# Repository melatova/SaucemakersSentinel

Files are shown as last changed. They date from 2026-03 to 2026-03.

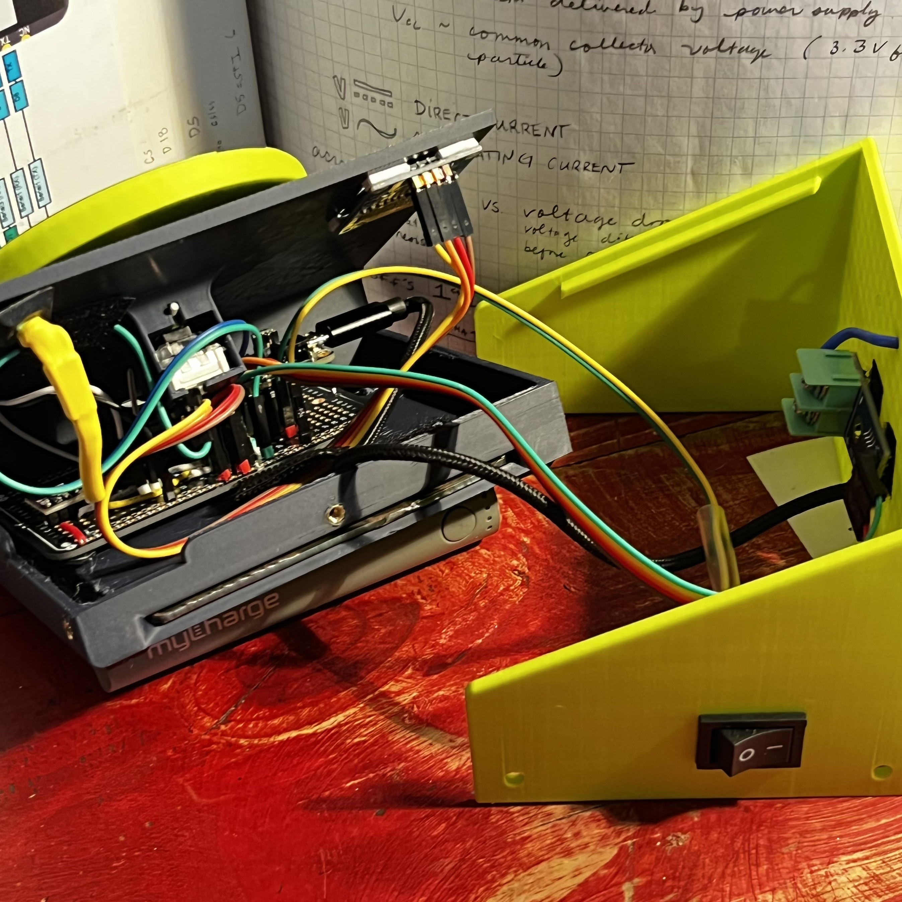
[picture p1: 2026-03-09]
Sentinel_IoT_Device/docs/assembly2.jpg

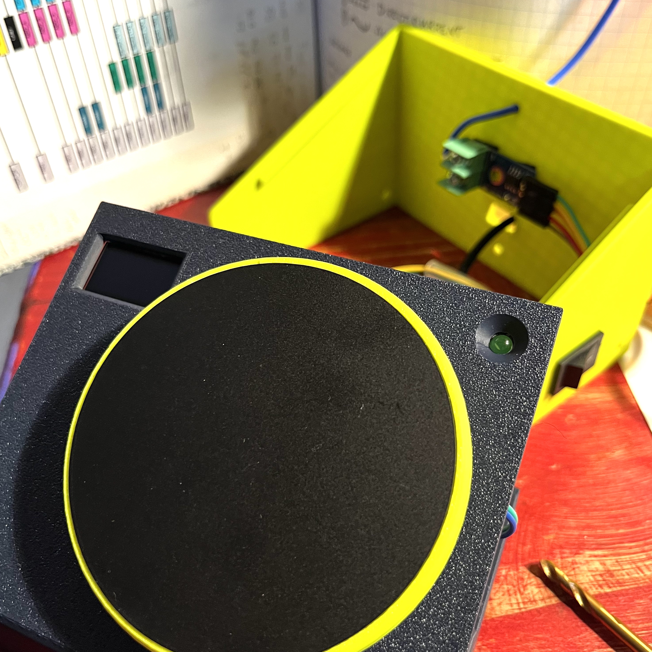
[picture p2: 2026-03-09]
Sentinel_IoT_Device/docs/assembly.jpg

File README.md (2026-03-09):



[]()
[]()

-------------------------------------------
--        Saucier’s Sentinel README      --
-------------------------------------------
          (^ . ^)  welcome!

Saucier’s Sentinel — A Hot Process Timer

A chef‑friendly IoT device that monitors a 10‑minute hot‑process cycle for sauce making.  
It reads a K‑type thermocouple, calculates the local boiling point from air pressure,  
and alerts the chef with a playful OLED UI, LED blinks, Philips Hue bulbs, and Wemo smart plugs.

* * * * * * * * * * * * * * * *

Features

  * Precise temperature monitoring** using a MAX6675 K‑type thermocouple  
  * Local boiling‑point calculation** using real‑time pressure from a BME280  
  * Chef‑friendly OLED UI** with animations, progress bar, and alert screens  
  * Smart kitchen integration**  
  * Philips Hue bulbs (blue = too cold, red = too hot)  
  * Wemo smart plugs (radio alert + stove cutoff)  
  * Single‑button interface**  
  * Short press -> start  
  * Long press -> cancel  
  * Stable state machine** for stable, predictable behavior  
  * Custom 3D‑printed enclosure** with slanted front, big easy-to-hit button and OLED window  

······························

System Architecture

loop()
├── readSensors()
├── updateButtons()
├── runStateMachine()
├── updateAlerts()
├── updateLED()
└── updateDisplay()

······························

Hardware

  * Particle Photon 2**
  * MAX6675 thermocouple amplifier**
  * K‑type thermocouple probe**
  * BME280 pressure + humidity sensor**
  * 128×64 SSD1306 OLED (I²C)**
  * Wemo smart plugs**
  * Philips Hue bulbs**
  * Custom 3D‑printed enclosure**

······························

Pinout

| Component | Pin |
|---|-----|
| Button | D6  |  
| LED | D7  |
| Thermocouple CS | D5  |
| Thermocouple SCK  | D4  |
| Thermocouple MISO | D3  |
| OLED SDA | D0  |
| OLED SCL | D1  |
| BME280 SDA | D0  |
| BME280 SCL | D1  |

······························

Local Boiling Point Calculation  
*(Clausius‑Clapeyron equation)*

```cpp
float calcBoilingPointC(float pressPA) {
    float pressHPA = pressPA / 100.0;
    float L  = 40650.0;
    float R  = 8.314;
    float T0 = 373.15;
    float P0 = 1013.25;

    float invT = (1.0 / T0) - (logf(pressHPA / P0) * R / L);
    return (1.0 / invT) - 273.15;
}

case SCREEN_CYCLE_IN_PROGRESS:
    if (cycleTimer.isTimerReady()) {
        currentScreen = SCREEN_SUCCESS;
        break;
    }
    if (tempF < TEMP_SAFE_LOW)  currentScreen = SCREEN_ALERT_LOW;
    if (tempF > TEMP_SAFE_HIGH) currentScreen = SCREEN_ALERT_HIGH;
    if (wasCancelHeld()) {
        cancelTimer.startTimer(CANCEL_MS);
        currentScreen = SCREEN_CANCELLING;
    }
    break;

······························

State Machine Core

case SCREEN_CYCLE_IN_PROGRESS:
    if (cycleTimer.isTimerReady()) {
        currentScreen = SCREEN_SUCCESS;
        break;
    }
    if (tempF < TEMP_SAFE_LOW)  currentScreen = SCREEN_ALERT_LOW;
    if (tempF > TEMP_SAFE_HIGH) currentScreen = SCREEN_ALERT_HIGH;
    if (wasCancelHeld()) {
        cancelTimer.startTimer(CANCEL_MS);
        currentScreen = SCREEN_CANCELLING;
    }
    break;

······························

OLED UI

Animated steam on loading screen

Big friendly temperature banner

Progress bar during cycle

Shiver animation (too cold)

Flame flicker (too hot)

Spinner animation (cancelling)

Sparkle animation (success)

······························

Enclosure

Designed in Onshape with:

Slanted ergonomic front

OLED window

Button recess

Thermocouple exit port

Internal mounting bosses

Smooth face blends and fillets

······························

Gallery

Enclosure files
(SaucemakersSentinel/Sentinel_IoT_device/enclosure/)

Internal layout
(SaucemakersSentinel/Sentinel_IoT_device/docs/Temp_monitor_device_fritzing_bb.png)
(SaucemakersSentinel/Sentinel_IoT_device/docs/Temp_monitor_device_fritzing_schem.png)

OLED UI photos
(SaucemakersSentinel/Sentinel_IoT_device/images/OLED_display.png)
(SaucemakersSentinel/Sentinel_IoT_device/images/OLED_Temp_Low.MOV)
(SaucemakersSentinel/Sentinel_IoT_device/images/OLED_complete.MOV)

Thermocouple in pot
(SaucemakersSentinel/Sentinel_IoT_device/images/Habanero_sauce.png)

Final assembled device 
(SaucemakersSentinel/Sentinel_IoT_device/images/device_with_active_screen_front.jpg)

······························

Files

/src — firmware

/enclosure — STLs

/images — photos + renders

/docs — diagrams + schematics

······························

Why This Exists
This project was created for a very special emerging hot‑sauce chef
who needed a reliable, friendly, and scientifically accurate way
to monitor the hot‑process cycle.

······························

License
MIT License — enjoy, remix, and cook boldly.

Project write‑up on Hackster.io:
https://www.hackster.io/melatova/saucier-s-sentinel-hot-process-timer-f0ca6f

[![Hackster Project](https://img.shields.io/badge/Hackster-Project-blue)](https://www.hackster.io/melatova/saucier-s-sentinel-hot-process-timer-f0ca6f)

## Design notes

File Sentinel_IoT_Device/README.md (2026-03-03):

# Sentinel_IoT_Device

This firmware project was created using [Particle Developer Tools](https://www.particle.io/developer-tools/) and is compatible with all [Particle Devices](https://www.particle.io/devices/).

Feel free to replace this README.md file with your own content, or keep it for reference.

## Table of Contents
- [Introduction](#introduction)
- [Prerequisites To Use This Template](#prerequisites-to-use-this-repository)
- [Getting Started](#getting-started)
- [Particle Firmware At A Glance](#particle-firmware-at-a-glance)
  - [Logging](#logging)
  - [Setup and Loop](#setup-and-loop)
  - [Delays and Timing](#delays-and-timing)
  - [Testing and Debugging](#testing-and-debugging)
  - [GitHub Actions (CI/CD)](#github-actions-cicd)
  - [OTA](#ota)
  - [Assets](#assets)
  - [Environment](#environment)
- [Support and Feedback](#support-and-feedback)
- [Version](#version)

## Introduction

For an in-depth understanding of this project template, please refer to our [documentation](https://docs.particle.io/firmware/best-practices/firmware-template/).

## Prerequisites To Use This Repository

To use this software/firmware on a device, you'll need:

- A [Particle Device](https://www.particle.io/devices/).
- Windows/Mac/Linux for building the software and flashing it to a device.
- [Particle Development Tools](https://docs.particle.io/getting-started/developer-tools/developer-tools/) installed and set up on your computer.
- Optionally, a nice cup of tea (and perhaps a biscuit).

## Getting Started

1. While not essential, we recommend running the [device setup process](https://setup.particle.io/) on your Particle device first. This ensures your device's firmware is up-to-date and you have a solid baseline to start from.

2. If you haven't already, open this project in Visual Studio Code (File -> Open Folder). Then [compile and flash](https://docs.particle.io/getting-started/developer-tools/workbench/#cloud-build-and-flash) your device. Ensure your device's USB port is connected to your computer.

3. Verify the device's operation by monitoring its logging output:
    - In Visual Studio Code with the Particle Plugin, open the [command palette](https://docs.particle.io/getting-started/developer-tools/workbench/#particle-commands) and choose "Particle: Serial Monitor".
    - Or, using the Particle CLI, execute:
    ```
    particle serial monitor --follow
    ```

4. Uncomment the code at the bottom of the cpp file in your src directory to publish to the Particle Cloud! Login to console.particle.io to view your devices events in real time.

5. Customize this project! For firmware details, see [Particle firmware](https://docs.particle.io/reference/device-os/api/introduction/getting-started/). For information on the project's directory structure, visit [this link](https://docs.particle.io/firmware/best-practices/firmware-template/#project-overview).

## Particle Firmware At A Glance

### Logging

The firmware includes a [logging library](https://docs.particle.io/reference/device-os/api/logging/logger-class/). You can display messages at different levels and filter them:

```
Log.trace("This is trace message");
Log.info("This is info message");
Log.warn("This is warn message");
Log.error("This is error message");
```

### Setup and Loop

Particle projects originate from the Wiring/Processing framework, which is based on C++. Typically, one-time setup functions are placed in `setup()`, and the main application runs from the `loop()` function.

For advanced scenarios, explore our [threading support](https://docs.particle.io/firmware/software-design/threading-explainer/).

### Delays and Timing

By default, the setup() and loop() functions are blocking whilst they run, meaning that if you put in a delay, your entire application will wait for that delay to finish before anything else can run. 

For techniques that allow you to run multiple tasks in parallel without creating threads, checkout the code example [here](https://docs.particle.io/firmware/best-practices/firmware-template/).

(Note: Although using `delay()` isn't recommended for best practices, it's acceptable for testing.)

### Testing and Debugging

For firmware testing and debugging guidance, check [this documentation](https://docs.particle.io/troubleshooting/guides/build-tools-troubleshooting/debugging-firmware-builds/).

### GitHub Actions (CI/CD)

This project provides a YAML file for GitHub, automating firmware compilation whenever changes are pushed. More details on [Particle GitHub Actions](https://docs.particle.io/firmware/best-practices/github-actions/) are available.

### OTA

To learn how to utilize Particle's OTA service for device updates, consult [this documentation](https://docs.particle.io/getting-started/cloud/ota-updates/).

Test OTA with the 'Particle: Cloud Flash' command in Visual Studio Code or the CLI command 'particle flash'!

This firmware supports binary assets in OTA packages, allowing the inclusion of audio, images, configurations, and external microcontroller firmware. More details are [here](https://docs.particle.io/reference/device-os/api/asset-ota/asset-ota/).

### Assets

To include assets in your OTA bundle, create an `assets` folder in your project root and place your files there. These can include audio files, images, configuration files, or firmware for external microcontrollers.

To enable asset OTA, uncomment the following line in `project.properties`:
```
assetOtaDir=assets
```

See the [Asset OTA documentation](https://docs.particle.io/reference/device-os/api/asset-ota) for more details.

### Environment

To bundle environment variables with your firmware, create an `env.json` file in your project root. Uncomment the following line in `project.properties` to enable it:
```
env=env.json
```

See the [Environment documentation](https://docs.particle.io/reference/device-os/api/environment) for more details.

## Support and Feedback

For support or feedback on this template or any Particle products, please join our [community](https://community.particle.io)!

## Version

Template version 1.0.3

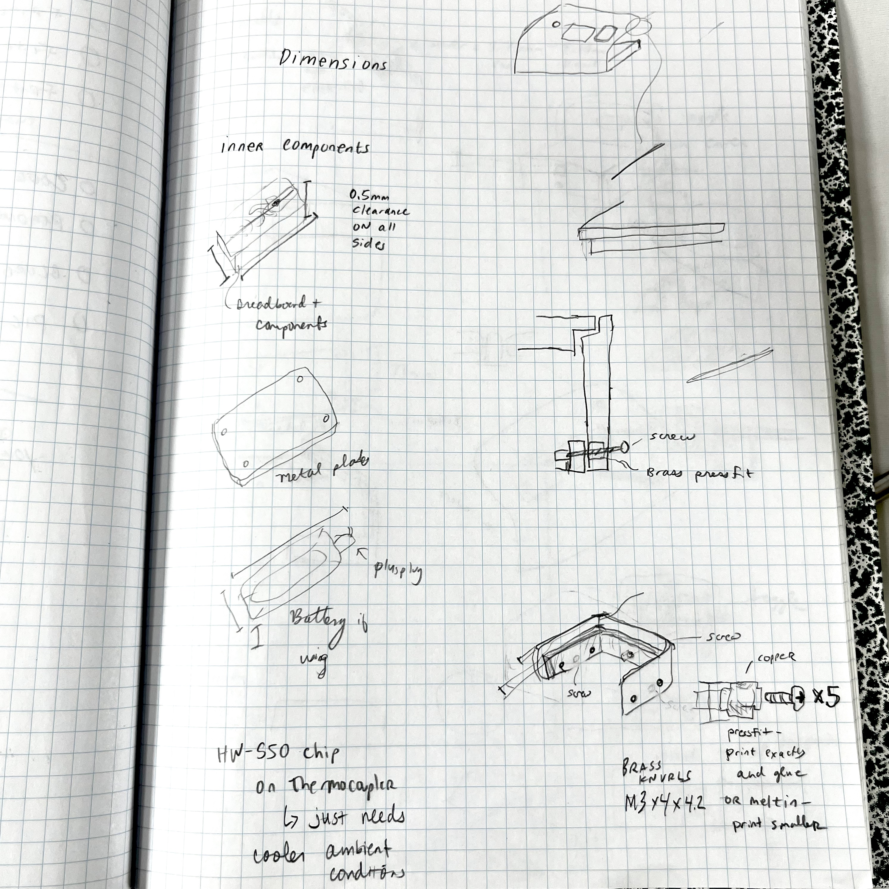
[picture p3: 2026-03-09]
Sentinel_IoT_Device/docs/Sketch_box_back.jpg

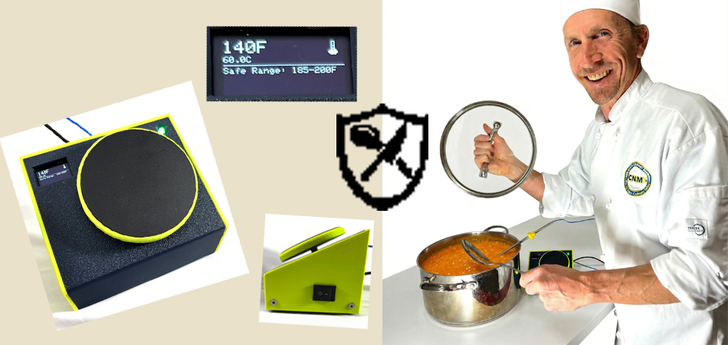
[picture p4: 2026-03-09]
Sentinel_IoT_Device/images/hackster_main.png

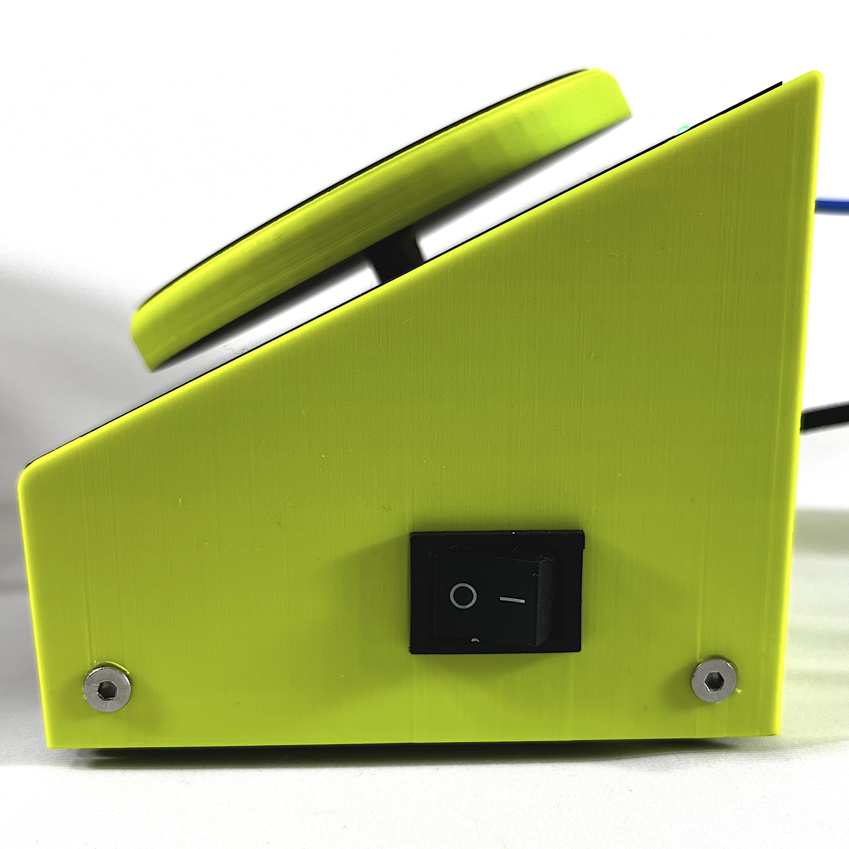
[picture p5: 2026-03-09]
Sentinel_IoT_Device/images/box_right_side.jpg

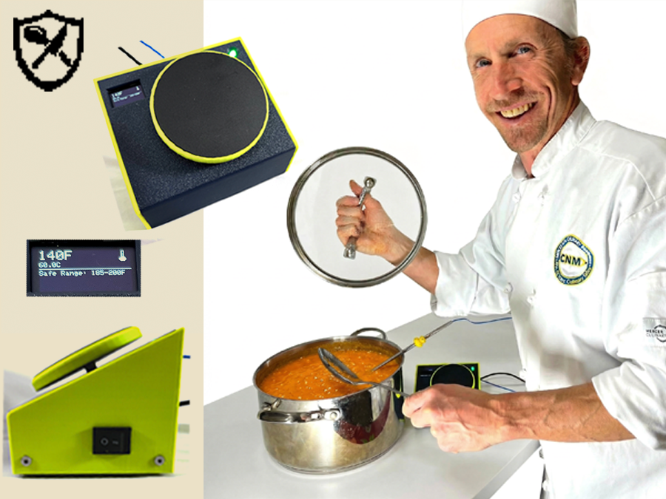
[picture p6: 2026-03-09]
Sentinel_IoT_Device/images/hackster_main2.png

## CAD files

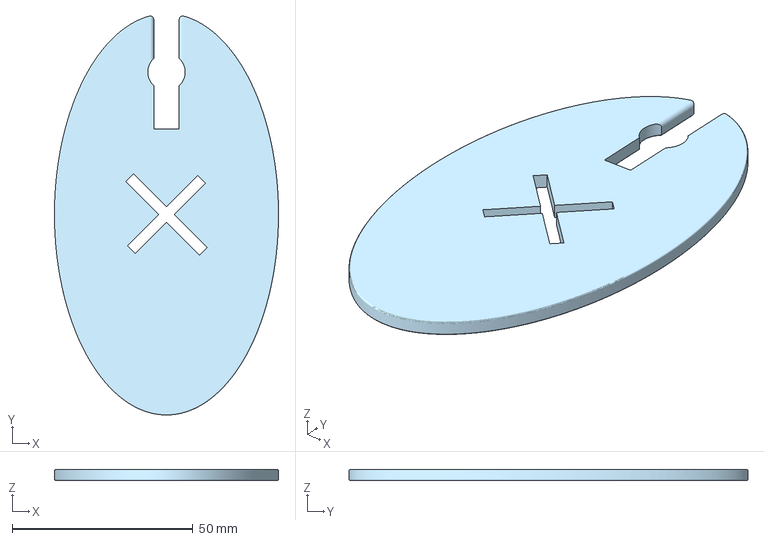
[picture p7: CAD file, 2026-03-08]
Sentinel_IoT_Device/docs/Duck holder - Part 1.3mf
62.0 x 110.4 x 3.00 mm

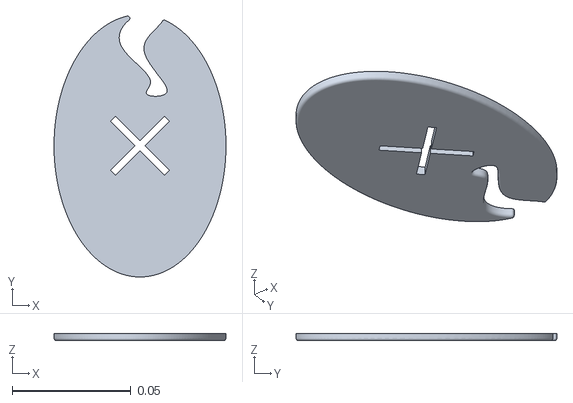
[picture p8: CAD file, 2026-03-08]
Sentinel_IoT_Device/enclosure/Duck holder - Part 2.stl
0.0725 x 0.11 x 0.003

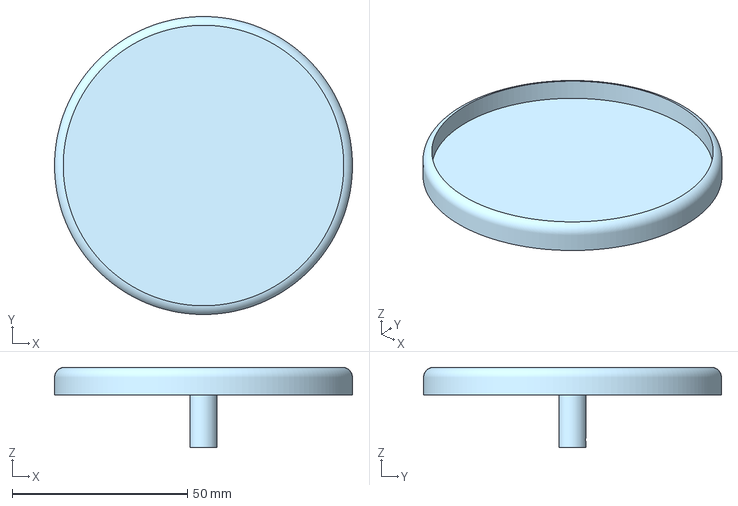
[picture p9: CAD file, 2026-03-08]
Sentinel_IoT_Device/docs/OLED_BME_Therm_Enclosure_Button.3mf
85.0 x 85.0 x 23.0 mm

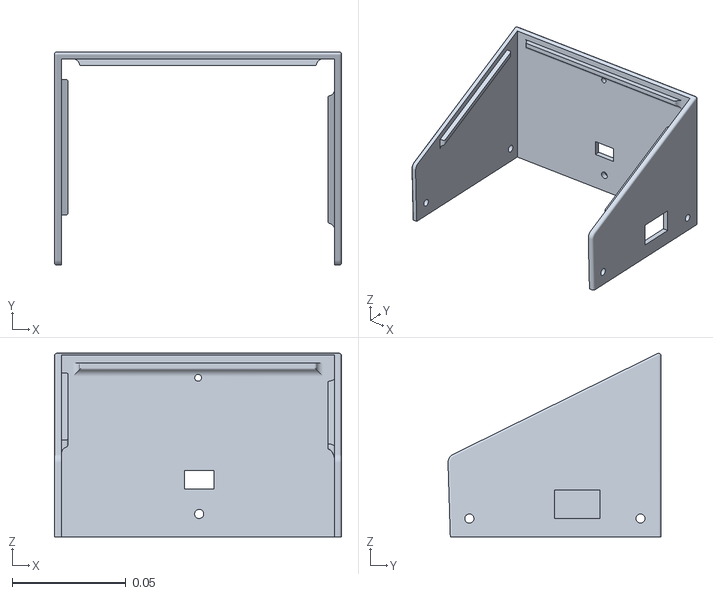
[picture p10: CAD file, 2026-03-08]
Sentinel_IoT_Device/enclosure/OLED_BME_Therm_Enclosure_Back.stl
0.126 x 0.0935 x 0.0806

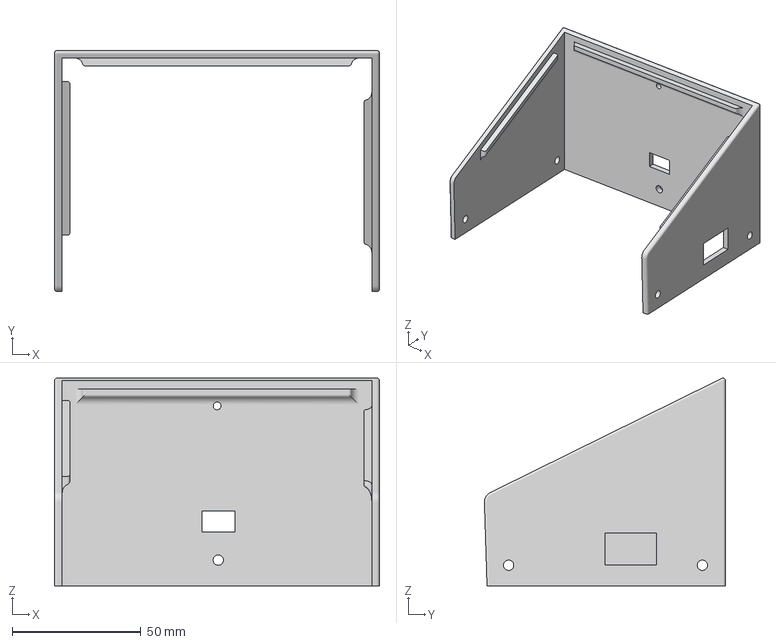
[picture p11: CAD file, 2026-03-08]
Sentinel_IoT_Device/docs/OLED_BME_Therm_Enclosure_Back.3mf
126.0 x 93.5 x 80.6 mm

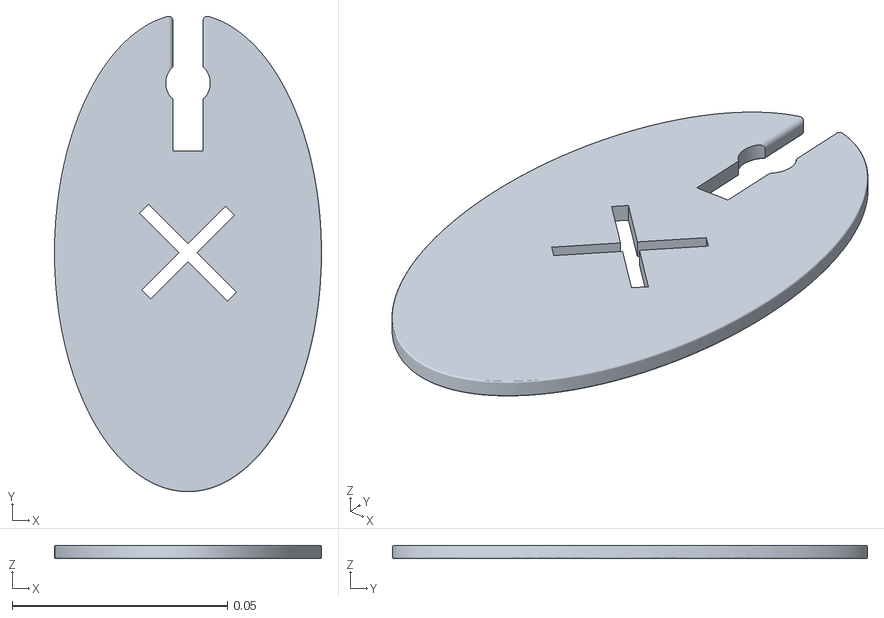
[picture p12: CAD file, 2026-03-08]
Sentinel_IoT_Device/enclosure/Duck holder - Part 1.stl
0.062 x 0.11 x 0.003

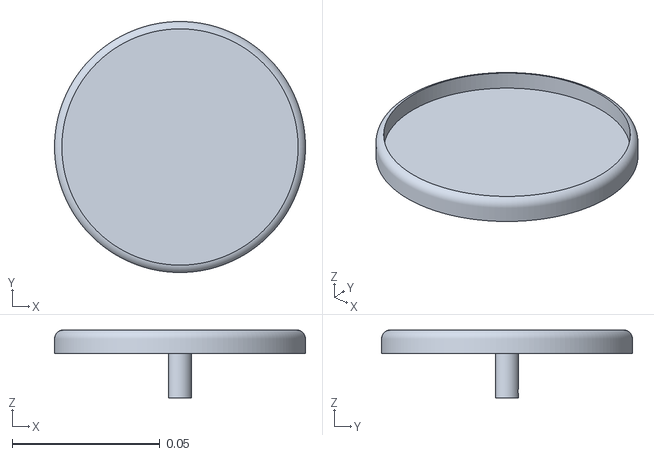
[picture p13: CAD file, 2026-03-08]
Sentinel_IoT_Device/enclosure/OLED_BME_Therm_Enclosure_Button.stl
0.085 x 0.085 x 0.023

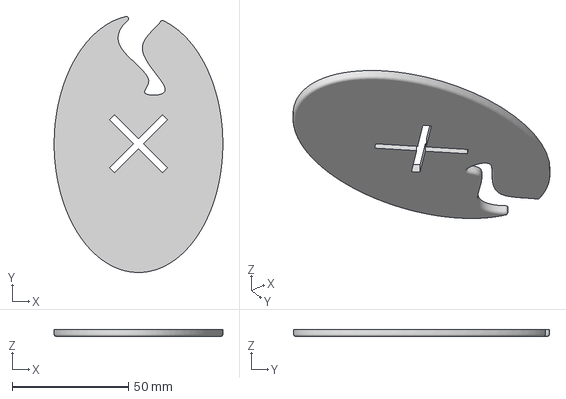
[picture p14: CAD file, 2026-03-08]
Sentinel_IoT_Device/docs/Duck holder - Part 2.3mf
72.5 x 109.9 x 3.00 mm

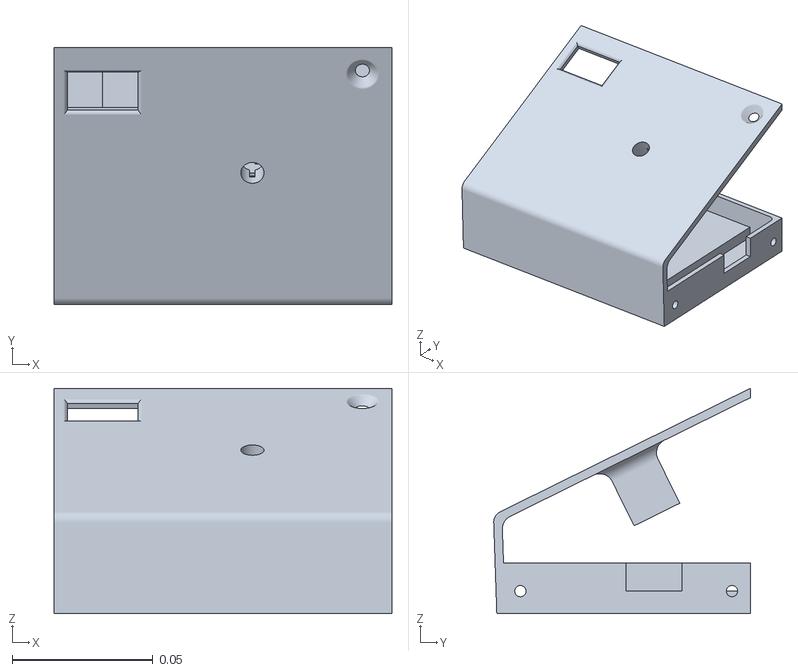
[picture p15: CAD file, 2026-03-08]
Sentinel_IoT_Device/enclosure/OLED_BME_Therm_Enclosure_Front.stl
0.12 x 0.0911 x 0.08

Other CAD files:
Sentinel_IoT_Device/docs/OLED_BME_Therm_Enclosure_Front.3mf

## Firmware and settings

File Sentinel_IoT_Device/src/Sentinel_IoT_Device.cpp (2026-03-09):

/*
 * Project:     Saucier’s Sentinel - Hot Process Timer
 * Author:      Nicole
 * Date:        03/07/2026
 *
 * Description:
 *   IoT temperature monitor for a 10-minute hot-process cycle.
 *   Tracks sauce temperature with a K-type thermocouple and alerts the
 *   chef via OLED display, Philips Hue bulbs, and Wemo smart plugs when
 *   the temperature drifts outside the safe range (185-200 degF).
 *   Also calculates the local boiling point from live air pressure —
 *   handy in Albuquerque, where water boils around 202 degF.
 *
 * Hardware pins:
 *   D7  — Power indicator LED (solid=idle, slow tick=timing, fast=done)
 *   D6  — Start/Cancel button (short press=start, hold 2s=cancel)
 *   D5  — Thermocouple CS   (MAX6675 chip select)
 *   D4  — Thermocouple SCK  (MAX6675 clock)
 *   D3  — Thermocouple MISO (MAX6675 data out)
 *   D1  — SCL: shared by OLED (SSD1306) and environment sensor (BME280)
 *   D0  — SDA: shared by OLED (SSD1306) and environment sensor (BME280)
 *   EN  — Hardware power switch
 *
 * Loop order every frame:
 *   readSensors → updateButtons → runStateMachine
 *   → updateAlerts → updateLED → updateDisplay
 *
 * Can change CYCLE_MS is set to 10000 (10 sec) for testing.
 *   Change to 600000 for the real 10-minute hot-process cycle.
 */


// ════════════════════════════════════════════════════════════════
//  LIBRARIES
// ════════════════════════════════════════════════════════════════

#include "Particle.h"
#include <math.h>              // logf() — used in boiling point calculation
#include "MAX6675.h"           // K-type thermocouple reader
#include "Adafruit_BME280.h"   // temperature / pressure / humidity sensor
#include "Adafruit_GFX.h"      // graphics resource (text, shapes)
#include "Adafruit_SSD1306.h"  // OLED display driver
#include "IoTTimer.h"          // non-blocking timers (no delay())
#include "bitmaps.h"           // original pixel art icons
#include "ui_theme.h"          // layout constants, font sizes, thresholds
#include "wemo.h"              // Wemo smart plug control
#include "hue.h"               // Philips Hue bulb control

SYSTEM_MODE(SEMI_AUTOMATIC);   // Call WiFi.connect() in setup()
SYSTEM_THREAD(ENABLED);        // keeps sensors and display responsive even if WiFi is slow


// ════════════════════════════════════════════════════════════════
//  DATA TYPES
// ════════════════════════════════════════════════════════════════

// The seven screens the device can be on at any moment.
// The state machine in runStateMachine() moves between these.
enum ScreenState {
    SCREEN_LOADING,            // loading screen while device warms up
    SCREEN_TEMP_MONITOR,       // idle — showing live temp, waiting to start
    SCREEN_CYCLE_IN_PROGRESS,  // timer running, temp in safe range
    SCREEN_ALERT_LOW,          // timer running, temp too cold
    SCREEN_ALERT_HIGH,         // timer running, temp too hot
    SCREEN_CANCELLING,         // chef held button — counting down to cancel
    SCREEN_SUCCESS,             // 10 minutes complete — safe to bottle!
    SCREEN_TIMER_SUCCESS        // 10 minutes complete! Just a kitchen timer.
};


// ════════════════════════════════════════════════════════════════
//  OBJECTS
// ════════════════════════════════════════════════════════════════

MAX6675          thermocouple;           // reads the probe in the pot
Adafruit_BME280  BME;                    // reads room pressure + humidity
Adafruit_SSD1306 display(-1);           // -1 = no hardware reset pin


// ════════════════════════════════════════════════════════════════
//  GLOBALS — constants
// ════════════════════════════════════════════════════════════════

// ── Hardware pins ────────────────────────────────────────────────
const int POWER_LEDPIN = D7;   // status LED
const int BUTTON_PIN   = D6;   // start/cancel button (INPUT_PULLUP: LOW=pressed)
const int BME_ADDRESS  = 0x76; // I2C address of BME280

// ── Hue bulbs and Wemo plugs ─────────────────────────────────────
const int BULB1     = 1;   // Hue bulb 1
const int BULB2     = 2;   // Hue bulb 2
const int WEMO_STOVE = 3;  // Wemo controlling the stove
const int WEMO_RADIO = 4;  // Wemo controlling the kitchen radio

// ── Button timing ────────────────────────────────────────────────
const unsigned long LONG_PRESS_MS = 2000;  // hold this long to cancel
const unsigned long DEBOUNCE_MS   =   20;  // ignore bounces shorter than this

// ── Cycle and screen timers ──────────────────────────────────────
// CYCLE_MS: how long the hot-process timer runs.
// Set to 10000 (10 sec) for testing, 600000 (10 min) for real hot-process.
const unsigned long LOADING_MS   =  7000;  // loading screen duration
const unsigned long CYCLE_MS     = 600000;  // change to 10000 for testing
const unsigned long CANCEL_MS    =  5000;  // cancelling animation duration
const unsigned long TEMP_READ_MS =   500;  // read sensors every 500ms


// ════════════════════════════════════════════════════════════════
//  GLOBALS — variables
// ════════════════════════════════════════════════════════════════

// ── Sensor readings ──────────────────────────────────────────────
float tempC    = 0.0;   // thermocouple reading in Celsius
float tempF    = 0.0;   // thermocouple reading in Fahrenheit
float pressPA  = 0.0;   // air pressure from BME280, raw Pascals
float humidRH  = 0.0;   // relative humidity from BME280 (reserved for future use)
float boilingF = 0.0;   // calculated local boiling point in degF

// ── State machine ────────────────────────────────────────────────
ScreenState currentScreen  = SCREEN_LOADING;
ScreenState previousScreen = SCREEN_LOADING;  // lets us detect screen transitions

// ── Cycle timing ─────────────────────────────────────────────────
unsigned long cycleStartTime = 0;   // millis() when chef pressed start
unsigned long cycleEndTime   = 0;   // millis() when cycle completed

// ── Button state ─────────────────────────────────────────────────
// Read the button directly with digitalRead() rather than the Button
// library — the library's debounce was causing bugs.
bool          buttonHeld              = false;
bool          buttonShortPress        = false;
bool          buttonReleasedAfterStart = false;  // prevents instant-cancel on start
unsigned long buttonPressStart        = 0;
bool          lastRawState            = HIGH;    // HIGH = not pressed (INPUT_PULLUP)
unsigned long lastDebounceTime        = 0;

// ── Alert state ──────────────────────────────────────────────────
bool alertsActive = false;   // true while Hue/Wemo are in alert state


// ════════════════════════════════════════════════════════════════
//  TIMERS
// ════════════════════════════════════════════════════════════════

IoTTimer loadingTimer;    // times the splash screen
IoTTimer cycleTimer;      // counts down the hot-process cycle
IoTTimer cancelTimer;     // counts down the cancelling animation
IoTTimer tempReadTimer;   // paces the sensor reads


// ════════════════════════════════════════════════════════════════
//  FUNCTION DECLARATIONS (prototypes)
// ════════════════════════════════════════════════════════════════
// Particle resolves these automatically, but listing them here
// matches the style guide and makes the structure easy to see at a glance.

void   initSensors();
float  calcBoilingPointC(float pressPA);
void   readThermocouple();
void   readBME();
void   updateButtons();
bool   wasShortPress();
bool   wasCancelHeld();
void   initTimers();
void   runStateMachine();
void   clearAlerts();
void   updateAlerts();
void   initDisplay();
void   drawTempBanner();
void   drawSeparator();
uint8_t animFrame(unsigned long speedMs, uint8_t numFrames);
void   displayLoadingScreen();
void   displayTempScreen();
void   displayCycleScreen();
void   displayLowAlertScreen();
void   displayHighAlertScreen();
void   displayCancellingScreen();
void   displaySuccessScreen();
void   displayTimerSuccessScreen();
void   updateLED();


// ════════════════════════════════════════════════════════════════
//  SETUP
// ════════════════════════════════════════════════════════════════

void setup() {
    Serial.begin(9600);
    waitFor(Serial.isConnected, 10000);

    pinMode(POWER_LEDPIN, OUTPUT);
    digitalWrite(POWER_LEDPIN, HIGH);
    pinMode(BUTTON_PIN, INPUT_PULLUP);

    initSensors();
    initTimers();
    initDisplay();

    currentScreen  = SCREEN_LOADING;
    previousScreen = SCREEN_LOADING;

    WiFi.on();
    WiFi.setCredentials("IoTNetwork");
    WiFi.connect();
}


// ════════════════════════════════════════════════════════════════
//  LOOP
// ════════════════════════════════════════════════════════════════

void loop() {

    // Read sensors every 500ms — no need for faster than that
    if (tempReadTimer.isTimerReady()) {
        readThermocouple();
        readBME();
        tempReadTimer.startTimer(TEMP_READ_MS);
    }

    updateButtons();      // check button, set button state
    runStateMachine();    // decide which screen we should be on
    updateAlerts();       // fire Hue/Wemo only on state transitions
    updateLED();          // blink the D7 LED to match current state

    // Draw whichever screen the state machine landed on
    switch (currentScreen) {
        case SCREEN_LOADING:           displayLoadingScreen();    break;
        case SCREEN_TEMP_MONITOR:      displayTempScreen();       break;
        case SCREEN_CYCLE_IN_PROGRESS: displayCycleScreen();      break;
        case SCREEN_ALERT_LOW:         displayLowAlertScreen();   break;
        case SCREEN_ALERT_HIGH:        displayHighAlertScreen();  break;
        case SCREEN_CANCELLING:        displayCancellingScreen(); break;
        case SCREEN_SUCCESS:           displaySuccessScreen();    break;
        case SCREEN_TIMER_SUCCESS:     displayTimerSuccessScreen(); break;
    }
}


// ════════════════════════════════════════════════════════════════
//  SENSOR FUNCTIONS
// ════════════════════════════════════════════════════════════════

// Start up the thermocouple and BME280 — must be called in setup().
void initSensors() {
    thermocouple.begin(D4, D5, D3);   // SCK=D4, CS=D5, MISO=D3
    BME.begin(BME_ADDRESS);
}

// Calculates the local boiling point of water from air pressure.
// This uses the Clausius-Clapeyron equation — the physics behind why
// pasta takes longer to cook in Denver (or Albuquerque!).
//
// Water boils when its own vapor pressure equals the surrounding air pressure.
// Less air pushing down = water escapes as steam at a lower temperature.
// At sea level (1013.25 hPa): returns 100 degC exactly.
// In Albuquerque (~834 hPa):  returns ~94-95 degC (~202 degF).
//
// pressPA: raw BME280 pressure reading in Pascals
// returns: boiling point in Celsius
float calcBoilingPointC(float pressPA) {
    float pressHPA = pressPA / 100.0;    // Pascals to hectopascals (hPa)
    float L        = 40650.0;            // latent heat of vaporization, water (J/mol)
    float R        =  8.314;             // universal gas constant (J/mol/K)
    float T0       = 373.15;             // sea-level boiling point in Kelvin (100 degC)
    float P0       = 1013.25;            // sea-level reference pressure (hPa)

    // Clausius-Clapeyron rearranged: 1/T = 1/T0 - (R/L) * ln(P/P0)
    float invT = (1.0 / T0) - (logf(pressHPA / P0) * R / L);
    return (1.0 / invT) - 273.15;       // convert Kelvin back to Celsius
}

// Reads the K-type thermocouple and converts to both Fahrenheit and Celsius.
void readThermocouple() {
    thermocouple.read();
    tempC = thermocouple.getTemperature();
    tempF = (9.0 / 5.0) * tempC + 32.0;
}

// Reads pressure and humidity from the BME280, then recalculates
// the local boiling point. Updates every 500ms, so even a passing
// storm front will shift the boiling point display slightly.
void readBME() {
    pressPA = BME.readPressure();   // raw Pascals
    humidRH = BME.readHumidity();   // % RH (reserved for future display)

    float boilC = calcBoilingPointC(pressPA);
    boilingF = boilC * 9.0 / 5.0 + 32.0;
}


// ════════════════════════════════════════════════════════════════
//  BUTTON FUNCTIONS
// ════════════════════════════════════════════════════════════════
//
// Using raw digitalRead() with manual debounce instead of the Button
// library. Debugging proved that this works better for this project.
//
// The button is wired INPUT_PULLUP:
//   HIGH = not pressed (the pull-up holds the pin high)
//   LOW  = pressed     (button connects pin to ground)
//
// On each loop frame:
//   - If the raw signal changed, reset the debounce timer.
//   - If the signal has been stable for DEBOUNCE_MS (20ms), treat it as real.
//   - Falling edge (HIGH to LOW): record when the press started.
//   - Rising edge  (LOW to HIGH): if held was short → note a short press.

// Reads the button each frame and updates the button state.
void updateButtons() {
    bool rawState = (digitalRead(BUTTON_PIN) == LOW);   // true = pressed

    // Reset the debounce clock whenever the raw signal changes
    if (rawState != lastRawState) {
        lastDebounceTime = millis();
        lastRawState     = rawState;
    }

    // Wait until the signal has settled before acting on it
    if ((millis() - lastDebounceTime) < DEBOUNCE_MS) {
        return;
    }

    bool down = rawState;   // signal is now stable

    // Once released, allow wasCancelHeld() to work (guards against instant cancel)
    if (!down) {
        buttonReleasedAfterStart = true;
    }

    // Falling edge: button just went down — record the time
    if (down && !buttonHeld) {
        buttonHeld       = true;
        buttonPressStart = millis();
        buttonShortPress = false;
    }

    // Rising edge: button just came up — was it a short tap?
    if (!down && buttonHeld) {
        buttonHeld = false;
        if ((millis() - buttonPressStart) < LONG_PRESS_MS) {
            buttonShortPress = true;   // consumed once by wasShortPress()
        }
    }
}

// Returns true once if a short press occurred, then resets the button state.
bool wasShortPress() {
    if (buttonShortPress) {
        buttonShortPress = false;
        return true;
    }
    return false;
}

// Returns true while the button has been held past LONG_PRESS_MS.
// The buttonReleasedAfterStart guard ensures the chef can't accidentally
// cancel the cycle the instant they let go of the start press.
bool wasCancelHeld() {
    return buttonHeld &&
           buttonReleasedAfterStart &&
           ((millis() - buttonPressStart) > LONG_PRESS_MS);
}


// ════════════════════════════════════════════════════════════════
//  TIMER INIT
// ════════════════════════════════════════════════════════════════

// Starts the two timers that run from the moment the device powers on.
// cycleTimer and cancelTimer are started later, triggered by button presses.
void initTimers() {
    loadingTimer.startTimer(LOADING_MS);
    tempReadTimer.startTimer(TEMP_READ_MS);
}


// ════════════════════════════════════════════════════════════════
//  STATE MACHINE
// ════════════════════════════════════════════════════════════════
//
// This is the brain of the device. Every loop, it checks the current
// screen and decides whether to stay or move to a new one.
//
// State map:
//
//   LOADING ──(7s)──> TEMP_MONITOR
//   TEMP_MONITOR ──(short press)──> CYCLE_IN_PROGRESS
//   CYCLE_IN_PROGRESS ──(timer done)──────────────────> SUCCESS
//   CYCLE_IN_PROGRESS ──(too cold)──> ALERT_LOW ──(ok)──> CYCLE_IN_PROGRESS
//   CYCLE_IN_PROGRESS ──(too hot)───> ALERT_HIGH ─(ok)──> CYCLE_IN_PROGRESS
//   ALERT_LOW  ──(timer done)──> TIMER_SUCCESS
//   ALERT_HIGH ──(timer done)──> TIMER_SUCCESS
//   Any active screen ──(hold 2s)──> CANCELLING ──(5s)──> TEMP_MONITOR
//   SUCCESS ──(short press)──> TEMP_MONITOR

void runStateMachine() {

    switch (currentScreen) {

        // Loading screen — wait for the timer to finish, then move to idle
        case SCREEN_LOADING:
            if (loadingTimer.isTimerReady()) {
                currentScreen = SCREEN_TEMP_MONITOR;
            }
            break;

        // Idle — watching temp, waiting for the chef to press start
        case SCREEN_TEMP_MONITOR:
            if (wasShortPress()) {
                // Reset button state so a lingering hold doesn't instantly cancel
                buttonHeld               = false;
                buttonPressStart         = 0;
                buttonReleasedAfterStart = false;
                cycleTimer.startTimer(CYCLE_MS);
                cycleStartTime = millis();
                currentScreen  = SCREEN_CYCLE_IN_PROGRESS;
            }
            break;

        // Cycle running — check for completion, temp problems, or cancel
        case SCREEN_CYCLE_IN_PROGRESS:
            if (cycleTimer.isTimerReady()) {
                cycleEndTime  = millis();
                currentScreen = SCREEN_SUCCESS;
                break;
            }
            if (tempF < TEMP_SAFE_LOW) {
                currentScreen = SCREEN_ALERT_LOW;
                break;
            }
            if (tempF > TEMP_SAFE_HIGH) {
                currentScreen = SCREEN_ALERT_HIGH;
                break;
            }
            if (wasCancelHeld()) {
                cancelTimer.startTimer(CANCEL_MS);
                currentScreen = SCREEN_CANCELLING;
            }
            break;

        // Too cold — timer still running, wait for temp to recover or cancel
        // Completion checked first so success is never missed
        case SCREEN_ALERT_LOW:
            if (cycleTimer.isTimerReady()) {
                cycleEndTime  = millis();
                currentScreen = SCREEN_TIMER_SUCCESS;
                break;
            }
            if (tempF >= TEMP_SAFE_LOW) {
                currentScreen = SCREEN_CYCLE_IN_PROGRESS;
                break;
            }
            if (wasCancelHeld()) {
                cancelTimer.startTimer(CANCEL_MS);
                currentScreen = SCREEN_CANCELLING;
            }
            break;

        // Too hot — same logic as too cold, just the opposite direction
        case SCREEN_ALERT_HIGH:
            if (cycleTimer.isTimerReady()) {
                cycleEndTime  = millis();
                currentScreen = SCREEN_TIMER_SUCCESS;
                break;
            }
            if (tempF <= TEMP_SAFE_HIGH) {
                currentScreen = SCREEN_CYCLE_IN_PROGRESS;
                break;
            }
            if (wasCancelHeld()) {
                cancelTimer.startTimer(CANCEL_MS);
                currentScreen = SCREEN_CANCELLING;
            }
            break;

        // Cancelling — show the animation, then return to idle
        case SCREEN_CANCELLING:
            if (cancelTimer.isTimerReady()) {
                currentScreen = SCREEN_TEMP_MONITOR;
            }
            break;

        // Success — wait for the chef to press the button to dismiss
        case SCREEN_SUCCESS:
            if (wasShortPress()) {
                currentScreen = SCREEN_TEMP_MONITOR;
            }
            break;

        // Timer success - 10 minutes has elapsed
        case SCREEN_TIMER_SUCCESS:
            if (wasShortPress()) {
                currentScreen = SCREEN_TEMP_MONITOR;
            }
            break;

        default:
            break;
    }
}


// ════════════════════════════════════════════════════════════════
//  ALERT FUNCTIONS (Hue bulbs + Wemo plugs)
// ════════════════════════════════════════════════════════════════

// Turns off alert lighting and hands stove control back to the chef.
void clearAlerts() {
    setHue(BULB1, false);
    setHue(BULB2, false);
    wemoWrite(WEMO_RADIO, LOW);
    wemoWrite(WEMO_STOVE, HIGH);   // stove back on — chef is in control
}

// Initiates Hue/Wemo commands only on screen transitions, not every frame.
// alertsActive prevents clearAlerts() from calling too many requests.
// 30+ times per second while nothing has actually changed.
void updateAlerts() {
    if (!WiFi.ready()) {
        return;
    }

    // If we've left an active screen, clear any lingering alerts
    bool inActive = (currentScreen == SCREEN_CYCLE_IN_PROGRESS ||
                     currentScreen == SCREEN_ALERT_LOW          ||
                     currentScreen == SCREEN_ALERT_HIGH);

    if (!inActive && alertsActive) {
        clearAlerts();
        alertsActive = false;
    }

    // TOO COLD transition: blue light + radio (audible cue in loud kitchen)
    if (currentScreen == SCREEN_ALERT_LOW && previousScreen != SCREEN_ALERT_LOW) {
        setHue(BULB1, true, HueBlue, 255, 255);
        wemoWrite(WEMO_RADIO, HIGH);
        alertsActive = true;
    }

    // TOO HOT transition: red light + radio + shut stove off
    if (currentScreen == SCREEN_ALERT_HIGH && previousScreen != SCREEN_ALERT_HIGH) {
        setHue(BULB1, true, HueRed, 255, 255);
        wemoWrite(WEMO_STOVE, LOW);
        wemoWrite(WEMO_RADIO, HIGH);
        alertsActive = true;
    }

    // Recovering back to in-range — cancel the alerts
    if (currentScreen == SCREEN_CYCLE_IN_PROGRESS &&
        (previousScreen == SCREEN_ALERT_LOW || previousScreen == SCREEN_ALERT_HIGH)) {
        clearAlerts();
        alertsActive = false;
    }

    previousScreen = currentScreen;
}


// ════════════════════════════════════════════════════════════════
//  DISPLAY FUNCTIONS
// ════════════════════════════════════════════════════════════════

// Starts up the OLED. Must be called in setup() before drawing anything.
void initDisplay() {
    display.begin(SSD1306_SWITCHCAPVCC, 0x3C);
    display.setTextColor(WHITE);
    display.clearDisplay();
    display.display();
}
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

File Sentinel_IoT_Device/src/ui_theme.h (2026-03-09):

/*
 * Project:     Saucier’s Sentinel - Hot Process Timer
 * File:        ui_theme.h  —  display layout, font sizes, and timing constants
 * Author:      Nicole
 * Date:        03/07/2026
 *
 * Move text rows, resize icons, or alter
 * animations — changing it here changes it globally.
 *
 * The display is a 128x64 pixel OLED (SSD1306, monochrome).
 * x goes left to right (0-127).
 * y goes top to bottom (0-63).
 *
 * ── SCREEN LAYOUT ───────────────────────────────────────────────
 *
 *   x=0                    x=110 x=127
 *   +──────────────────────+─────+  y=0
 *   |  BIG degF  (size 2)  |16x16|  y=0-15   <- temperature + icon
 *   +──────────────────────+ icon|
 *   |  small degC (size 1) |     |  y=18-25  <- secondary temp
 *   +──────────────────────+─────+  y=28     <- separator line
 *   |  status row                |  y=31     <- e.g. "Left: 09:47"
 *   |  message row 1             |  y=41     <- e.g. "Turn up heat"
 *   |  message row 2             |  y=52     <- e.g. "Hold 2s cancel"
 *   +────────────────────────────+  y=63
 *
 *   Progress bar (cycle screen only) lives below the messages:
 *   +── full width, y=56 to y=62
 */

#ifndef UI_THEME_H
#define UI_THEME_H


// ── FONT SIZES ───────────────────────────────────────────────────
// Adafruit GFX text size multiplies the base 6x8px character.
// Size 1 = 6x8px  (fits 21 chars across 128px — labels)
// Size 2 = 12x16px (fits 10 chars — the big temperature number)
const int FONT_HERO     = 2;   // big degF temperature reading, top-left
const int FONT_HEADLINE = 2;   // screen titles like "BRAVO!" and "CANCELLING"
const int FONT_BODY     = 1;   // all labels and messages


// ── TEMPERATURE THRESHOLDS ───────────────────────────────────────
// Hot-process safety range per FDA guidelines.
// The state machine in main cpp reads these.
// Changing them here updates them everywhere.
const float TEMP_SAFE_LOW  = 185.0;   // degF — below this: sauce not safe yet
const float TEMP_SAFE_HIGH = 200.0;   // degF — above this: sauce could scorch


// ── SCREEN DIMENSIONS ────────────────────────────────────────────
const int SCREEN_W = 128;   // pixels wide
const int SCREEN_H =  64;   // pixels tall


// ── ICON (16x16, top-right corner) ──────────────────────────────
// Each screen draws its own icon here. The x position is calculated
// so the icon's right edge lands 2px from the screen edge.
const int ICON_W       = 16;
const int ICON_H       = 16;
const int ICON_X_RIGHT = 110;   // = SCREEN_W(128) - ICON_W(16) - margin(2)
const int ICON_Y       =   0;   // icons always sit at the very top


// ── TEMPERATURE BANNER (top-left, rows 0-27) ─────────────────────
// Big degF number sits at the top-left corner.
// The smaller degC reading appears just below it.
const int TEMP_X  =  0;   // degF text: left edge of screen
const int TEMP_Y  =  0;   // degF text: top of screen
const int TEMPC_X =  0;   // degC text: same left edge
const int TEMPC_Y = 18;   // degC text: 16px font height + 2px breathing room


// ── SEPARATOR LINE ───────────────────────────────────────────────
// A horizontal line drawn across the full width at this y position.
// Divides the temperature area (top) from messages (bottom).
const int SEPARATOR_Y = 28;


// ── MESSAGE ROWS (below separator) ───────────────────────────────
// Three text rows, each using FONT_BODY (8px tall).
// ROW_STATUS is the most prominent — timers and alert titles live here.
const int ROW_STATUS = 31;   // top row: status, timer, or alert title
const int ROW_MSG1   = 41;   // middle row: instructions or description
const int ROW_MSG2   = 52;   // bottom row: secondary message


// ── PROGRESS BAR (cycle screen only) ────────────────────────────
// A full-width bar in the bottom strip that fills as the cycle runs.
// It sits below ROW_MSG2 so they do not overlap.
const int PROG_X = 0;     // left edge
const int PROG_Y = 56;    // just below the last text row
const int PROG_W = 128;   // full screen width
const int PROG_H = 6;     // 6px tall — bottom lands at y=62, 1px from edge


// ── ANIMATION TIMING ─────────────────────────────────────────────
// How many milliseconds each animation frame is shown on screen.
// Larger number = slower animation. These are used by animFrame().
const int ANIM_SPEED =  200;   // general sparkles and steam puffs
const int SHIVER_MS  =  150;   // thermometer shiver on too-cold alert
const int FLASH_MS   =  120;   // flame flicker on too-hot alert
const int SPINNER_MS =  150;   // the /-\| spinner on cancelling screen


// ── LAYOUT GRID HELPERS ──────────────────────────────────────────
// Handy spacing values if you ever add new UI elements.
const int GRID_SMALL  =  4;
const int GRID_MEDIUM =  8;
const int GRID_LARGE  = 12;


#endif // UI_THEME_H

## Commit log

2026-03-06 updates to code fri
    [Temp_monitor_device_fritzing.fzz]
2026-03-08 updates to project
    [Duck holder - Part 1.3mf, Duck holder - Part 1.stl, Duck holder - Part 2.3mf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]
2026-03-09 readme and stls
    [Duck holder - Part 1.3mf, Duck holder - Part 1.stl, Duck holder - Part 2.3mf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]
